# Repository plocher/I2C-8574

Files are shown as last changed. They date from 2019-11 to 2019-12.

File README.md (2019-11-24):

# I2C-8574
## License: CERN Open Hardware Licence v1.2

I2C PCF8474-based IO Expander with 4x IO4 connections

### Introduction

This board was originally produced to help me build control panels for
my model railroad - I needed to connect many different buttons, switches
and lights to an Arduino, and also connect the Arduino to a
communications bus (Ethernet, CAN or Loconet), and I couldn\'t find
anything that had both high IO point density AND visual feedback.

I started with a simple Arduino
[ShowMeShield](/pages/ShowMeShield "wikilink") with Active-Low monitoring LEDs on each pin.
I quickly iterated (understatement) through at least a dozen designs, trying to
discern what worked well and what didn\'t.  I\'ll spare you the details...
I was aiming to support up to the max I2C devices that can be used together; 
for the PCF8474 series, that would be 8x devices of each type, for a total of 16x8, or 128 i/o points.

(Active-LOW means that the LOGICAL "ON" state is when the PHYSICAL state is low.
In this case, the indication LED is on when the desired pin is grounded; 
when programming, writing a \"1\" to an Active Low port will cause it to ground).

### Cautions

With several hundred IO loads, and up to 32 external breakout devices, a
suitable power supply needs to be used.

In practice, a 2A 9-12VDC supply a good choice.

This supply needs to power the Arduino, its direct IO loads, the I2C
expander chain AND provide \~100mA to each IO4 device. Instead of
relying on the Arduino\'s onboard regulated supply (which is only good
for about 100mA itself), each board has its own regulator, and there is
a common supply feed that can handle about 2.5A @ 12v. If more power is
needed, the daisy chained power feed thru can be replaced with a
per-board independent supply.

### Specifications

This IO board is based on the 8574 I2C 8-bit IO Expander, with a
buffered LED driver (discrete P-FETs) connected to a
bank of LEDs that show the status of the I/O lines in real time.

Each board provides a latched set of 16x IO points, with each point
being software selectable to be either an input or an output. The
individual points are reasonably protected from the environment, and can
easily drive or sink 10 mA each. By using active low inputs and outputs, the
effects of environmental noise are reduced - remote sensors only need to
ground an I/O point to register activity.

#### Communication Protocol {#communication_protocol}

``` {.cpp}
Simple I2C Reads and Writes:
int I2Cextender::read8(int i2caddr) {
    int _data = -1;
    Wire.requestFrom(i2caddr, 1);
    if(Wire.available()) {
      _data = Wire.receive();
    }
    return _data;
}

void I2Cextender::write8(int i2caddr, int data)
{ 
    Wire.beginTransmission(i2caddr);
    Wire.send(0xff & data);
    Wire.endTransmission();  
}
```

See [I2Cexpander](https://github.com/plocher/I2Cexpander) for a more complete interface library.

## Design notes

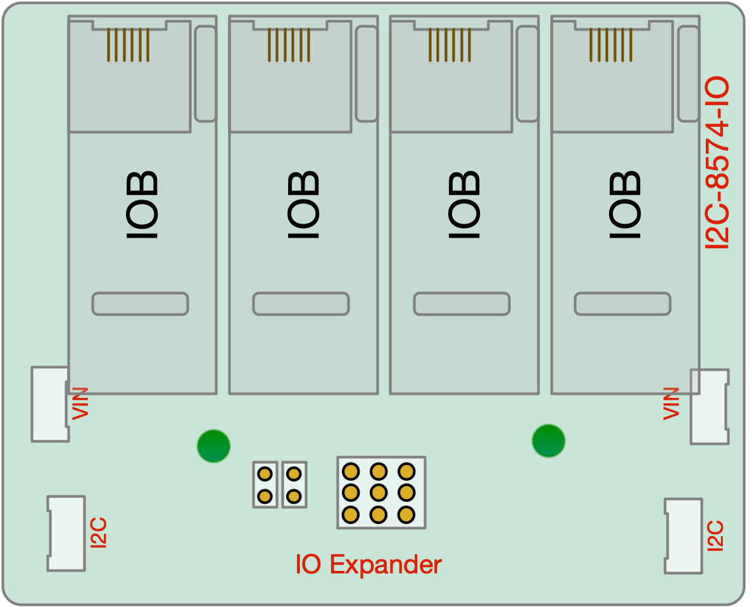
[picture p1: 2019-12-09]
I2C-8574-Graphic.png

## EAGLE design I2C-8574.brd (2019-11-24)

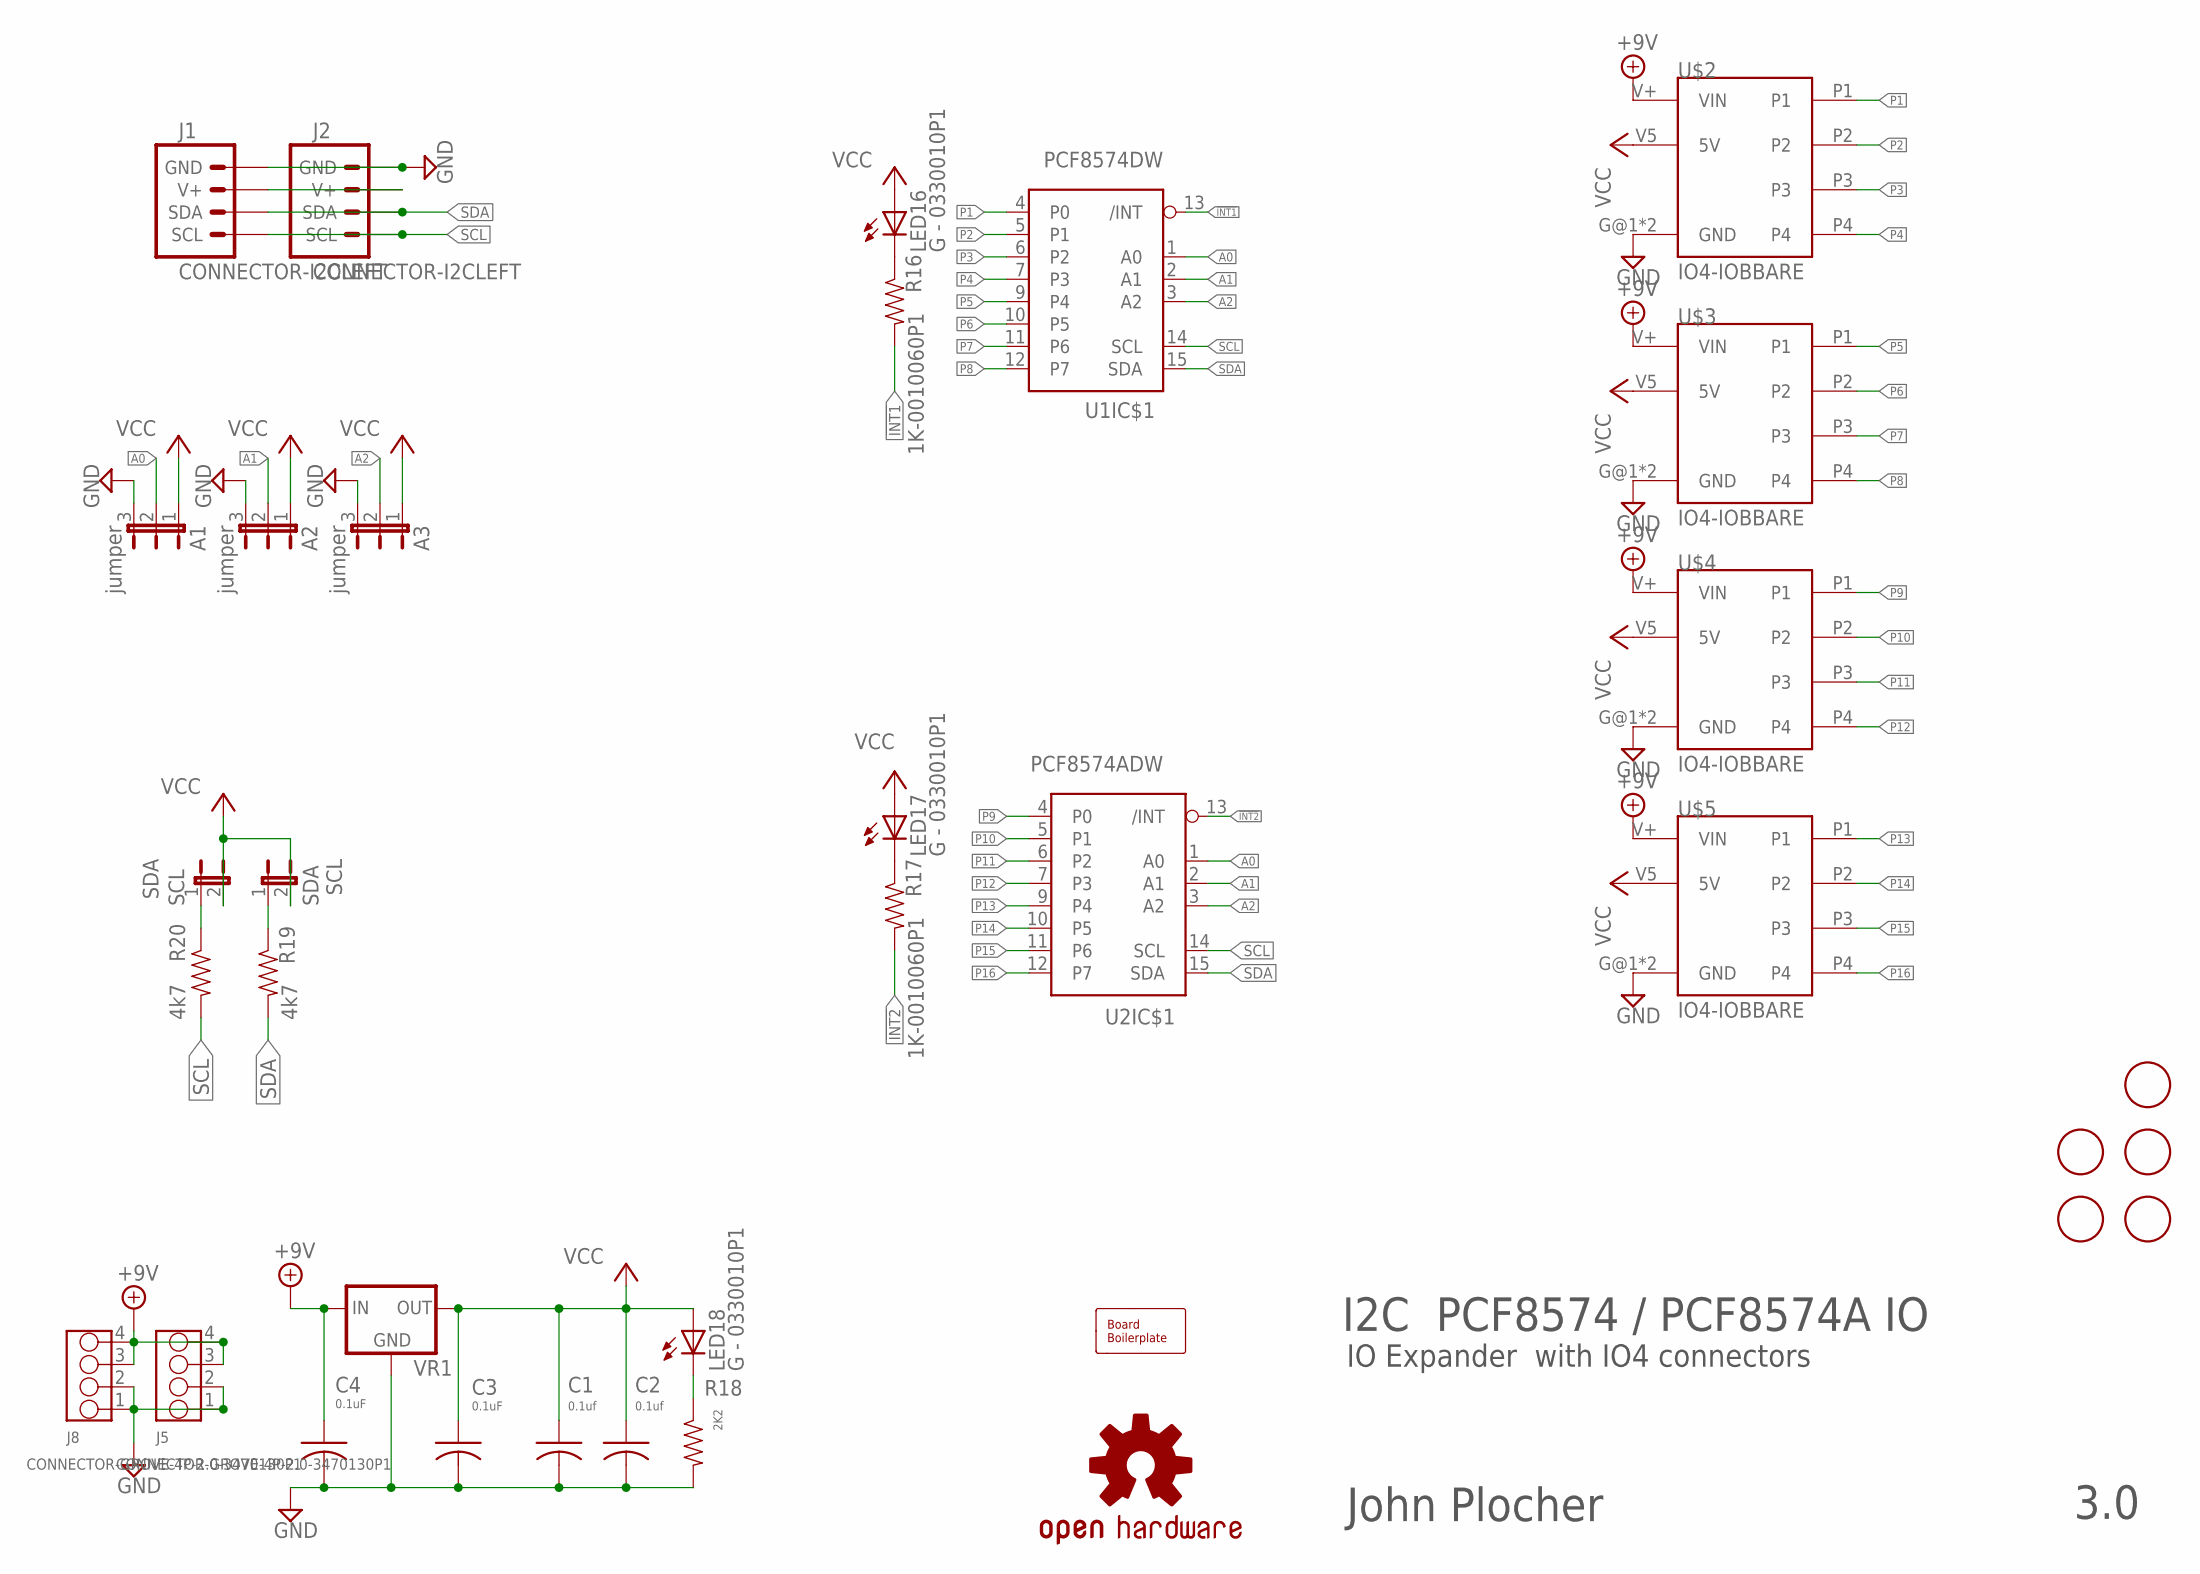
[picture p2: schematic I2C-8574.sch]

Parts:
A1, A2, A3: jumper; 1X03
BOARD1: BOARD80X100-NOHOLES; BOARD-DINRAIL-3.17IN-NOHOLES
C1, C2: 0.1uf; 0805-CAP
C3, C4: 0.1uF; 0805-CAP
FID1, FID2, FID3: FIDUCIAL; FIDUCIAL_1MM
FID-U1, FID-U2: FIDUCIAL; FIDUCIAL_1MM
J1, J2: CONNECTOR-I2CLEFT; I2C-L
J5, J8: CONNECTOR-GROVE-4P-2.0-3470130P1; 4P-2.0
LED16, LED17, LED18: G - 0330010P1; 0603-LED
R16, R17: 1K-0010060P1; 0805-RES
R18: 2K2; 0805-RES
R19, R20: 4k7; 0805-RES
SCL: SDA; 1X02_LOCK
SDA: SCL; 1X02_LOCK
U1: PCF8574DW; SO-16DW
U2: PCF8574ADW; SO-16DW
U$1: OSHW-LOGOL; OSHW-LOGO-L
U$2, U$3, U$4, U$5: IO4-IOBBARE; IO4-IOB
VR1: VREG-DPAK-5; TO-252

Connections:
!INT1: R16.2, U1.13 (/INT)
!INT2: R17.2, U2.13 (/INT)
+9V: C4.1, J5.3, J5.4, J8.3, J8.4, U$2.V+ (VIN), U$3.V+ (VIN), U$4.V+ (VIN), U$5.V+ (VIN), VR1.1 (IN)
A0: A1.2, U1.1 (A0), U2.1 (A0)
A1: A2.2, U1.2 (A1), U2.2 (A1)
A2: A3.2, U1.3 (A2), U2.3 (A2)
GND: A1.3, A2.3, A3.3, C1.2, C2.2, C3.2, C4.2, J1.GND, J1.GND@1 (GND), J2.GND, J2.GND@1 (GND), J5.1, J5.2, J8.1, J8.2, R18.2, U1.8 (GND), U2.8 (GND), U$2.G@1 (GND), U$2.G@2 (GND), U$3.G@1 (GND), U$3.G@2 (GND), U$4.G@1 (GND), U$4.G@2 (GND), U$5.G@1 (GND), U$5.G@2 (GND), VR1.2 (GND)
unnamed: LED18.C, R18.1
unnamed: R19.1, SCL.1
unnamed: R20.1, SDA.1
unnamed: LED17.C, R17.1
unnamed: LED16.C, R16.1
unnamed: J1.V+, J1.V+@1 (V+), J2.V+, J2.V+@1 (V+)
P1: U1.4 (P0), U$2.P1
P2: U1.5 (P1), U$2.P2
P3: U1.6 (P2), U$2.P3
P4: U1.7 (P3), U$2.P4
P5: U1.9 (P4), U$3.P1
P6: U1.10 (P5), U$3.P2
P7: U1.11 (P6), U$3.P3
P8: U1.12 (P7), U$3.P4
P9: U2.4 (P0), U$4.P1
P10: U2.5 (P1), U$4.P2
P11: U2.6 (P2), U$4.P3
P12: U2.7 (P3), U$4.P4
P13: U2.9 (P4), U$5.P1
P14: U2.10 (P5), U$5.P2
P15: U2.11 (P6), U$5.P3
P16: U2.12 (P7), U$5.P4
SCL: J1.SCL, J1.SCL@1 (SCL), J2.SCL, J2.SCL@1 (SCL), R20.2, U1.14 (SCL), U2.14 (SCL)
SDA: J1.SDA, J1.SDA@1 (SDA), J2.SDA, J2.SDA@1 (SDA), R19.2, U1.15 (SDA), U2.15 (SDA)
VCC: A1.1, A2.1, A3.1, C1.1, C2.1, C3.1, LED16.A, LED17.A, LED18.A, SCL.2, SDA.2, U1.16 (VCC), U2.16 (VCC), U$2.V5 (5V), U$3.V5 (5V), U$4.V5 (5V), U$5.V5 (5V), VR1.3 (OUT)

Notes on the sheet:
I2C PCF8574 / PCF8574A IO
IO Expander with IO4 connectors
John Plocher
3.0

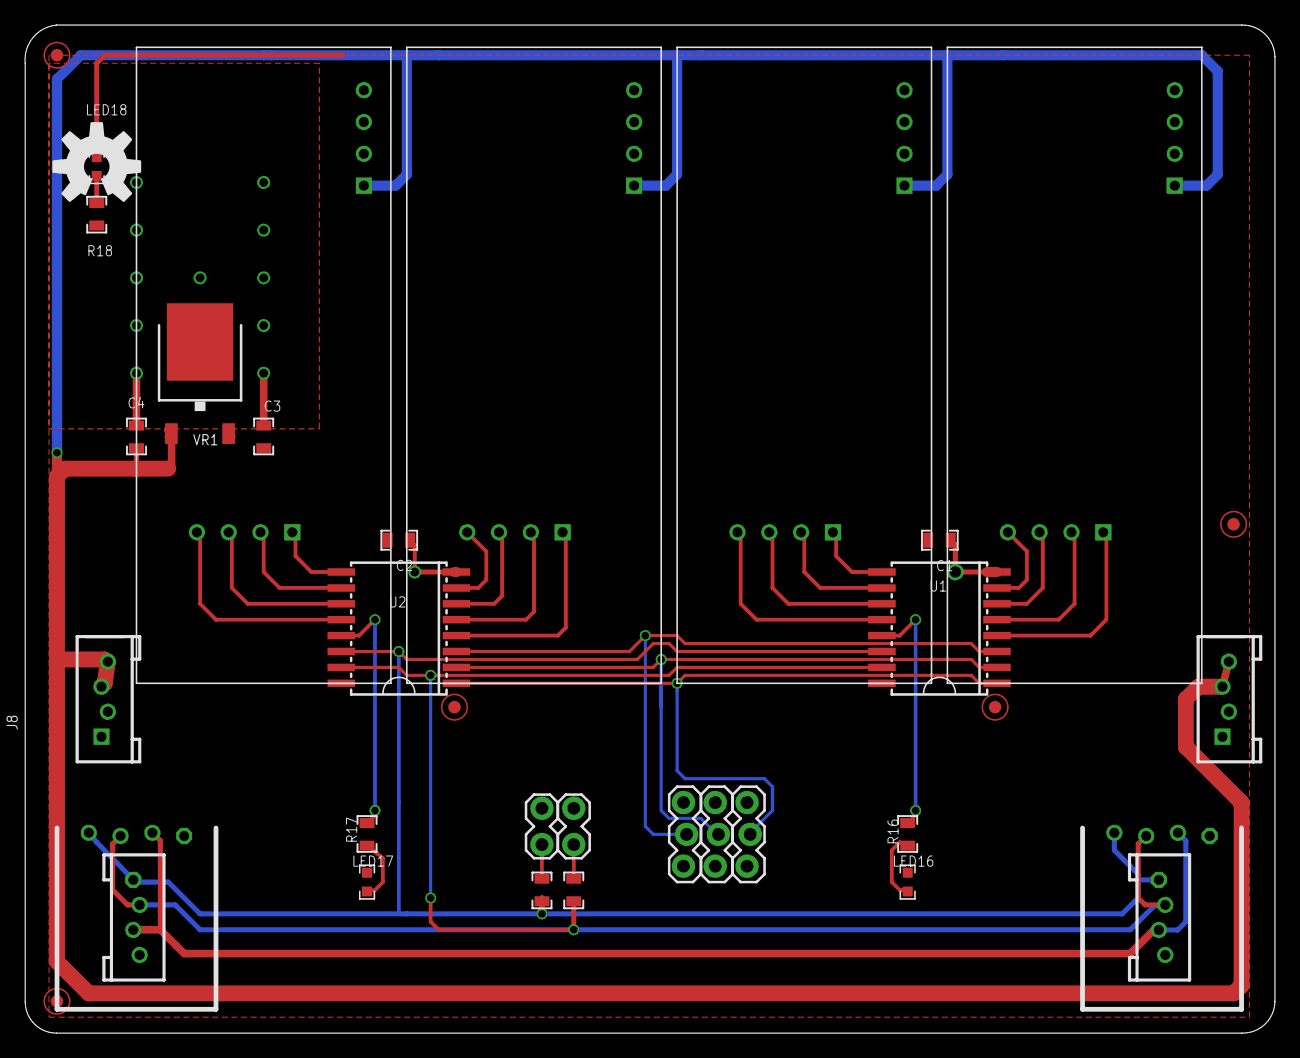
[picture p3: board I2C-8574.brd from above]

Board: 2 copper layers, 99.8 x 80.5 mm, 35 parts (0 on the bottom side), 32 nets.
